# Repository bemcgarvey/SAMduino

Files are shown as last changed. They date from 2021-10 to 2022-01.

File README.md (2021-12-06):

# SAMduino

## A demonstartion board for the ATSAMV71N21B microcontroller.  Includes firmware projects to demonstrate many modules and features.  
  
### There is sample firmware for:
* Basic gpio and interrupts
* DMA
* High speed USB
* QSPI with a SST26VF064B flash
* CAN-FD
* ADC and DAC
* PWM
* True random number generator
* TWI
* RTC
* USB bootloader
* High speed USB mass storage device with QSPI flash
* etc

### All firmware is built in MPLabX with MPLab Harmony 3 and the XC32 compiler.  
### Schematic and PCB were made with KiCAD

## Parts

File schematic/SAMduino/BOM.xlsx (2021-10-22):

Reference | Quantity | Value | Footprint
C1 C5 C6 C8 C9 C11 C14 C16 C17 C18 C19 C21 C22 C24 C25 | 15 | 100n | Capacitor_SMD:C_0402_1005Metric
C7 C10 | 2 | 10uF | Capacitor_SMD:C_0805_2012Metric
C12 C13 | 2 | 22uF | Capacitor_SMD:C_0603_1608Metric
C15 C20 | 2 | 4.7uF | Capacitor_SMD:C_0603_1608Metric
C23 | 1 | 1uF | Capacitor_SMD:C_0402_1005Metric
C28 | 1 | 220n | Capacitor_SMD:C_0603_1608Metric
C2 C3 | 2 | 20p | Capacitor_SMD:C_0603_1608Metric
C26 C27 C29 C30 | 4 | 100n | Capacitor_SMD:C_0603_1608Metric
C4 | 1 | 10p | Capacitor_SMD:C_0603_1608Metric
D1 D2 | 2 | MBR0520LT | Diode_SMD:D_SOD-123
D3 | 1 | Green | LED_SMD:LED_0603_1608Metric
D4 | 1 | Yellow | LED_SMD:LED_0603_1608Metric
D5 | 1 | Red | LED_SMD:LED_0805_2012Metric
D6 | 1 | Green | LED_SMD:LED_0805_2012Metric
D7 | 1 | Blue | LED_SMD:LED_0805_2012Metric
D8 | 1 | Yellow | LED_SMD:LED_0805_2012Metric
D9 D11 | 2 | Red | LED_SMD:LED_0603_1608Metric
IC1 | 1 | ATSAMV71N21B-AABT | SamacSys_Parts:QFP50P1600X1600X160-100N
IC2 | 1 | AZ1117CH-5.0TRG1 | SOT230P700X180-4N
IC3 | 1 | AZ1117IH-3.3TRG1 | SOT230P700X180-4N
IC4 | 1 | SST26VF064B-104V_SM | SamacSys_Parts:SOIC127P794X203-8N
IC5 | 1 | MCP2221-I_SL | SamacSys_Parts:SOIC127P600X175-14N
IC6 | 1 | MCP2542FD-E_SN | SamacSys_Parts:SOIC127P600X175-8N
J1 | 1 | Barrel_Jack_Switch | Connector_BarrelJack:BarrelJack_Wuerth_6941xx301002
J10 | 1 | Conn_02x11_Odd_Even | Connector_PinHeader_2.54mm:PinHeader_2x11_P2.54mm_Vertical
J11 J12 | 2 | Conn_02x09_Odd_Even | Connector_PinHeader_2.54mm:PinHeader_2x09_P2.54mm_Vertical
J15 J17 J19 | 3 | Conn_02x03_Odd_Even | Connector_PinHeader_2.54mm:PinHeader_2x03_P2.54mm_Vertical
J2 J14 J18 | 3 | Conn_02x02_Odd_Even | Connector_PinHeader_2.54mm:PinHeader_2x02_P2.54mm_Vertical
J20 | 1 | Conn_01x08 | Connector_PinHeader_2.54mm:PinHeader_1x08_P2.54mm_Horizontal
J3 | 1 | USB_B_Micro | Connector_USB:USB_Micro-B_Amphenol_10104110_Horizontal
J4 | 1 | USB_B_Mini | Connector_USB:USB_Mini-B_Wuerth_65100516121_Horizontal
J5 J7 J8 J13 J16 | 5 | Conn_01x02 | Connector_PinHeader_2.54mm:PinHeader_1x02_P2.54mm_Vertical
J6 | 1 | Screw_Terminal_01x02 | SamacSys_Parts:1725656
J9 | 1 | Conn_02x07_Odd_Even | Connector_PinHeader_2.54mm:PinHeader_2x07_P2.54mm_Vertical
L1 | 1 | 10uH | Inductor_SMD:L_0603_1608Metric
L2 L3 L4 | 3 | 470R | Inductor_SMD:L_0603_1608Metric
R1 | 1 | 5k62 ± 1% | Resistor_SMD:R_0402_1005Metric
R14 R15 | 2 | 4k7 | Resistor_SMD:R_0603_1608Metric
R5 R6 R9 R10 R11 R12 R18 | 7 | 220R | Resistor_SMD:R_0603_1608Metric
R19 | 1 | 330R | Resistor_SMD:R_0603_1608Metric
R2 | 1 | 22k | Resistor_SMD:R_0603_1608Metric
R13 R20 | 2 | 10k | Resistor_SMD:R_0603_1608Metric
R3 | 1 | 15k | Resistor_SMD:R_0603_1608Metric
R4 R8 R16 R17 | 4 | 100k | Resistor_SMD:R_0603_1608Metric
R7 | 1 | 120R | Resistor_SMD:R_0805_2012Metric
SW1 SW2 | 2 | SW_MEC_5E | SamacSys_Parts:FSM16JH
SW3 | 1 | MCLR | SamacSys_Parts:PTS647SK38SMTR2LFS
SW4 | 1 | ERASE | SamacSys_Parts:PTS647SK38SMTR2LFS
X1 | 1 | 12 MHz | SamacSys_Parts:ASTMUPCE3312000MHZLJET
X2 | 1 | 32.768 kHz 12.5 pF | SamacSys_Parts:CM9VT1A

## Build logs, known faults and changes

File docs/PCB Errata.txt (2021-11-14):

SAMduino errata

V1.0 pcb
	Button labels are reversed.  Left button is PD8, right is PA20
	CAN connector - CANL and CANH are mislabeled.  They are reversed.

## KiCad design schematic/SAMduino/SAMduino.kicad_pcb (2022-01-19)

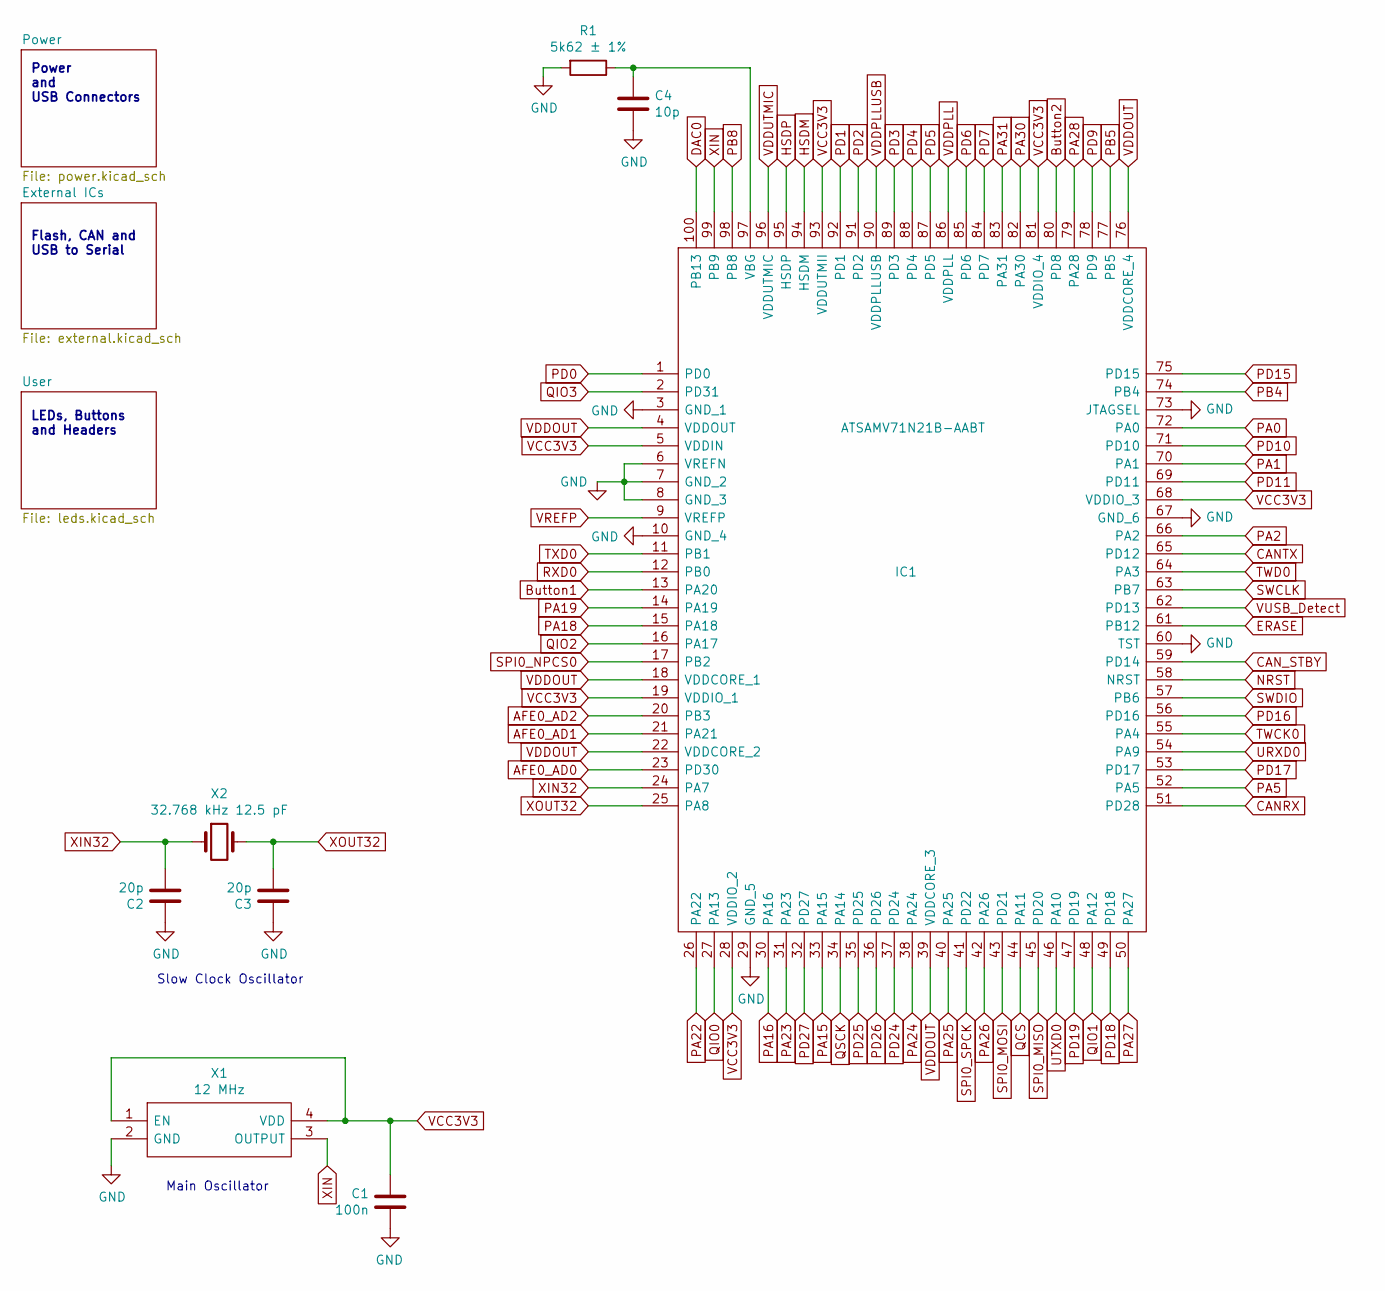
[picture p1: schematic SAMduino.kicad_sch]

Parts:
C1: 100n; C_0402_1005Metric
C2, C3: 20p; C_0603_1608Metric
C4: 10p; C_0603_1608Metric
IC1: ATSAMV71N21B-AABT; QFP50P1600X1600X160-100N; Mouser Part Number 556-ATSAMV71N21BAABT
R1: 5k62 ± 1%; R_0402_1005Metric
X1: 12 MHz; ASTMUPCE3312000MHZLJET
X2: 32.768 kHz 12.5 pF; CM9VT1A; Part Number CM9V-T1A-32.768kHz-12.5pF-20PPM-TA-QC; Mouser Part Number 428-202257-MC01

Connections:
AFE0_AD0: IC1.23 (PD30); also elsewhere on the board
AFE0_AD1: IC1.21 (PA21); also elsewhere on the board
AFE0_AD2: IC1.20 (PB3); also elsewhere on the board
Button1: IC1.13 (PA20); also elsewhere on the board
Button2: IC1.80 (PD8); also elsewhere on the board
CANRX: IC1.51 (PD28); also elsewhere on the board
CANTX: IC1.65 (PD12); also elsewhere on the board
CAN_STBY: IC1.59 (PD14); also elsewhere on the board
DAC0: IC1.100 (PB13); also elsewhere on the board
ERASE: IC1.61 (PB12); also elsewhere on the board
GND: C1.2, C2.1, C3.1, C4.2, IC1.3 (GND_1), IC1.6 (VREFN), IC1.7 (GND_2), IC1.8 (GND_3), IC1.10 (GND_4), IC1.29 (GND_5), IC1.60 (TST), IC1.67 (GND_6), IC1.73 (JTAGSEL), R1.2, X1.2 (GND); also elsewhere on the board
HSDM: IC1.94 (HSDM); also elsewhere on the board
HSDP: IC1.95 (HSDP); also elsewhere on the board
NRST: IC1.58 (NRST); also elsewhere on the board
unnamed: C4.1, IC1.97 (VBG), R1.1
PA0: IC1.72 (PA0); also elsewhere on the board
PA1: IC1.70 (PA1); also elsewhere on the board
PA2: IC1.66 (PA2); also elsewhere on the board
PA5: IC1.52 (PA5); also elsewhere on the board
PA15: IC1.33 (PA15); also elsewhere on the board
PA16: IC1.30 (PA16); also elsewhere on the board
PA18: IC1.15 (PA18); also elsewhere on the board
PA19: IC1.14 (PA19); also elsewhere on the board
PA22: IC1.26 (PA22); also elsewhere on the board
PA23: IC1.31 (PA23); also elsewhere on the board
PA24: IC1.38 (PA24); also elsewhere on the board
PA25: IC1.40 (PA25); also elsewhere on the board
PA26: IC1.42 (PA26); also elsewhere on the board
PA27: IC1.50 (PA27); also elsewhere on the board
PA28: IC1.79 (PA28); also elsewhere on the board
PA30: IC1.82 (PA30); also elsewhere on the board
PA31: IC1.83 (PA31); also elsewhere on the board
PB4: IC1.74 (PB4); also elsewhere on the board
PB5: IC1.77 (PB5); also elsewhere on the board
PB8: IC1.98 (PB8); also elsewhere on the board
PD0: IC1.1 (PD0); also elsewhere on the board
PD1: IC1.92 (PD1); also elsewhere on the board
PD2: IC1.91 (PD2); also elsewhere on the board
PD3: IC1.89 (PD3); also elsewhere on the board
PD4: IC1.88 (PD4); also elsewhere on the board
PD5: IC1.87 (PD5); also elsewhere on the board
PD6: IC1.85 (PD6); also elsewhere on the board
PD7: IC1.84 (PD7); also elsewhere on the board
PD9: IC1.78 (PD9); also elsewhere on the board
PD10: IC1.71 (PD10); also elsewhere on the board
PD11: IC1.69 (PD11); also elsewhere on the board
PD15: IC1.75 (PD15); also elsewhere on the board
PD16: IC1.56 (PD16); also elsewhere on the board
PD17: IC1.53 (PD17); also elsewhere on the board
PD18: IC1.49 (PD18); also elsewhere on the board
PD19: IC1.47 (PD19); also elsewhere on the board
PD24: IC1.37 (PD24); also elsewhere on the board
PD25: IC1.35 (PD25); also elsewhere on the board
PD26: IC1.36 (PD26); also elsewhere on the board
PD27: IC1.32 (PD27); also elsewhere on the board
QCS: IC1.44 (PA11); also elsewhere on the board
QIO0: IC1.27 (PA13); also elsewhere on the board
QIO1: IC1.48 (PA12); also elsewhere on the board
QIO2: IC1.16 (PA17); also elsewhere on the board
QIO3: IC1.2 (PD31); also elsewhere on the board
QSCK: IC1.34 (PA14); also elsewhere on the board
RXD0: IC1.12 (PB0); also elsewhere on the board
SPI0_MISO: IC1.45 (PD20); also elsewhere on the board
SPI0_MOSI: IC1.43 (PD21); also elsewhere on the board
SPI0_NPCS0: IC1.17 (PB2); also elsewhere on the board
SPI0_SPCK: IC1.41 (PD22); also elsewhere on the board
SWCLK: IC1.63 (PB7); also elsewhere on the board
SWDIO: IC1.57 (PB6); also elsewhere on the board
TWCK0: IC1.55 (PA4); also elsewhere on the board
TWD0: IC1.64 (PA3); also elsewhere on the board
TXD0: IC1.11 (PB1); also elsewhere on the board
URXD0: IC1.54 (PA9); also elsewhere on the board
UTXD0: IC1.46 (PA10); also elsewhere on the board
VCC3V3: C1.1, IC1.5 (VDDIN), IC1.19 (VDDIO_1), IC1.28 (VDDIO_2), IC1.68 (VDDIO_3), IC1.81 (VDDIO_4), IC1.93 (VDDUTMII), X1.1 (EN), X1.4 (VDD); also elsewhere on the board
VDDOUT: IC1.4 (VDDOUT), IC1.18 (VDDCORE_1), IC1.22 (VDDCORE_2), IC1.39 (VDDCORE_3), IC1.76 (VDDCORE_4); also elsewhere on the board
VDDPLL: IC1.86 (VDDPLL); also elsewhere on the board
VDDPLLUSB: IC1.90 (VDDPLLUSB); also elsewhere on the board
VDDUTMIC: IC1.96 (VDDUTMIC); also elsewhere on the board
VREFP: IC1.9 (VREFP); also elsewhere on the board
VUSB_Detect: IC1.62 (PD13); also elsewhere on the board
XIN: IC1.99 (PB9), X1.3 (OUTPUT)
XIN32: C2.2, IC1.24 (PA7), X2.1
XOUT32: C3.2, IC1.25 (PA8), X2.2

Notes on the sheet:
Main Oscillator
Flash, CAN and USB to Serial
LEDs, Buttons and Headers
Slow Clock Oscillator
Power and USB Connectors

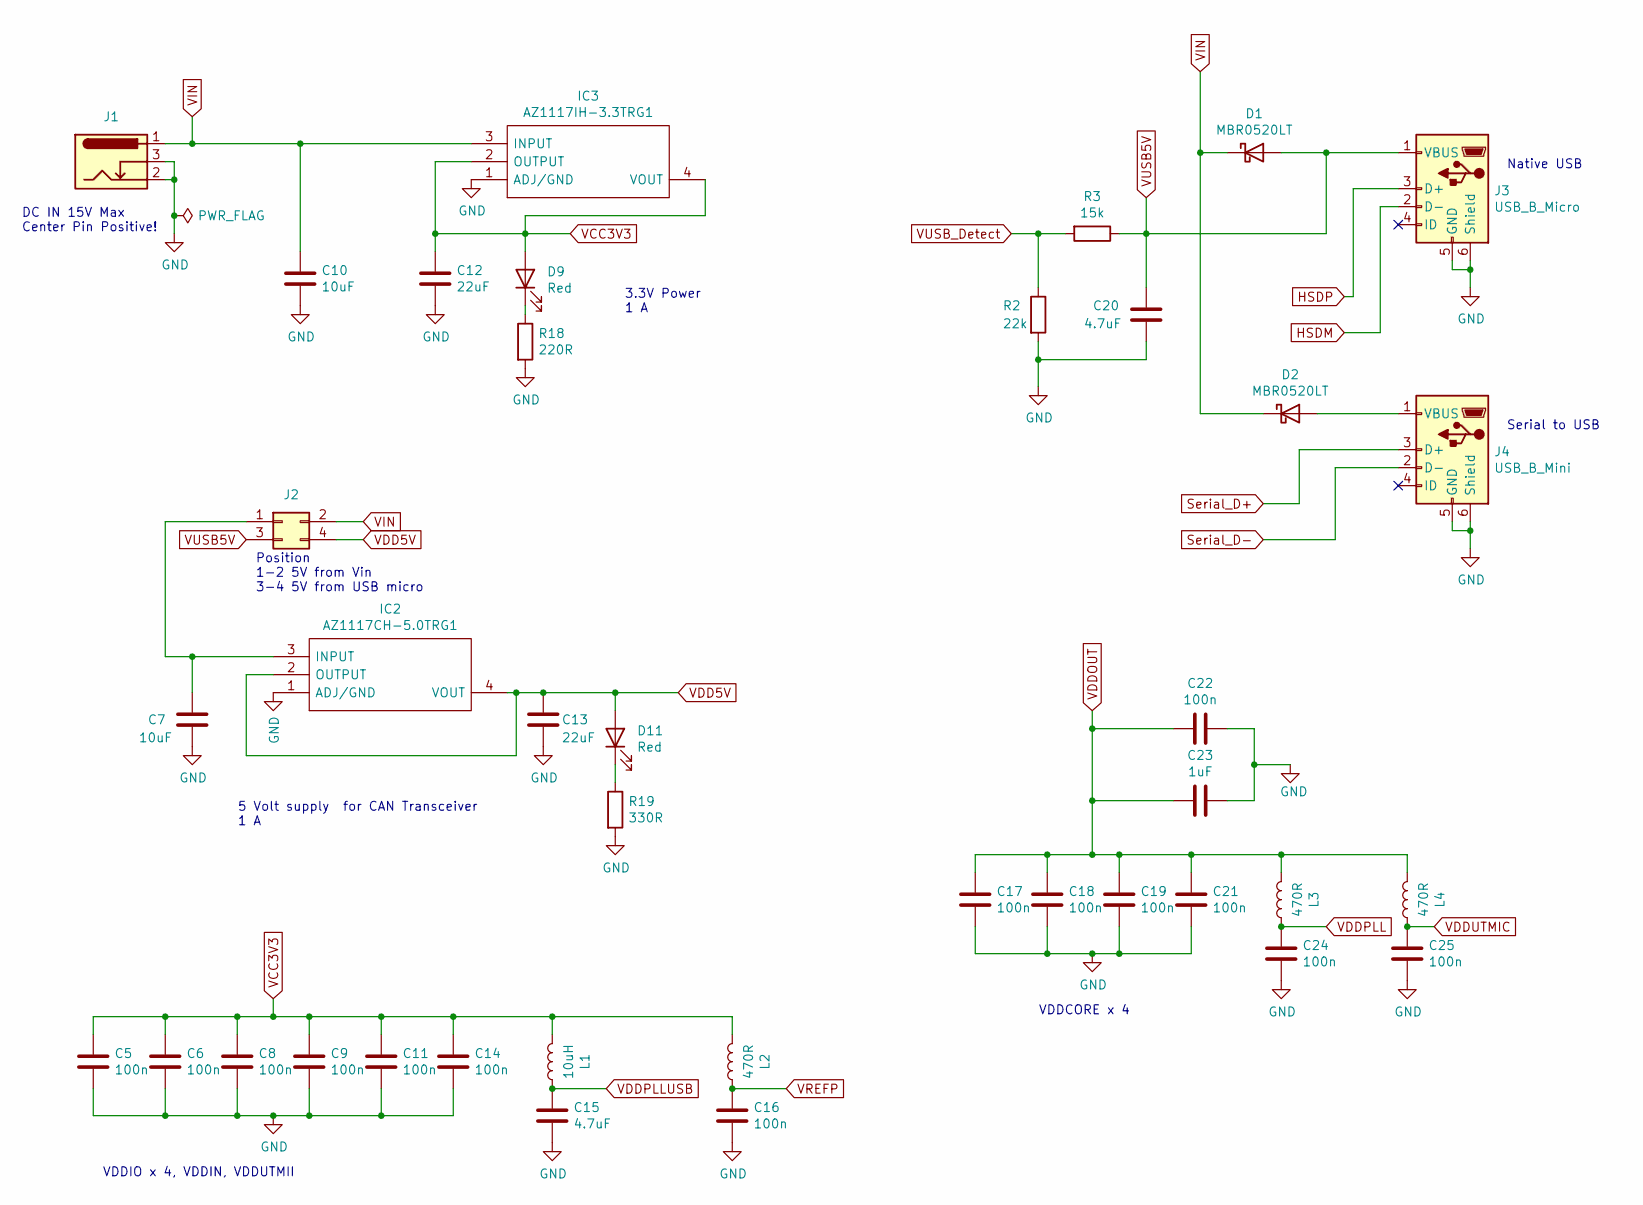
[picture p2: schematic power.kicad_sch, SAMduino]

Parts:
C5, C6, C8, C9, C11, C14, C16, C17, C18, C19, C21, C22, C24, C25: 100n; C_0402_1005Metric
C7, C10: 10uF; C_0805_2012Metric
C12, C13: 22uF; C_0603_1608Metric
C15, C20: 4.7uF; C_0603_1608Metric
C23: 1uF; C_0402_1005Metric
D1, D2: MBR0520LT; D_SOD-123
D9, D11: Red; LED_0603_1608Metric
IC2: AZ1117CH-5.0TRG1; SOT230P700X180-4N; Mouser Part Number 621-AZ1117CH-5.0TRG1
IC3: AZ1117IH-3.3TRG1; SOT230P700X180-4N; Mouser Part Number 621-AZ1117IH-3.3TRG1
J1: Barrel_Jack_Switch; BarrelJack_Wuerth_6941xx301002
J2: Conn_02x02_Odd_Even; PinHeader_2x02_P2.54mm_Vertical
J3: USB_B_Micro; USB_Micro-B_Amphenol_10104110_Horizontal
J4: USB_B_Mini; USB_Mini-B_Wuerth_65100516121_Horizontal
L1: 10uH; L_0603_1608Metric
L2, L3, L4: 470R; L_0603_1608Metric
R2: 22k; R_0603_1608Metric
R3: 15k; R_0603_1608Metric
R18: 220R; R_0603_1608Metric
R19: 330R; R_0603_1608Metric

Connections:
GND: C5.2, C6.2, C7.2, C8.2, C9.2, C10.2, C11.2, C12.2, C13.2, C14.2, C15.2, C16.2, C17.2, C18.2, C19.2, C20.2, C21.2, C22.1, C23.1, C24.2, C25.2, IC2.1 (ADJ/GND), IC3.1 (ADJ/GND), J1.2, J1.3, J3.5 (GND), J3.6 (Shield), J4.5 (GND), J4.6 (Shield), R2.2, R18.2, R19.2; also elsewhere on the board
HSDM: J3.2 (D-); also elsewhere on the board
HSDP: J3.3 (D+); also elsewhere on the board
unnamed: C7.1, IC2.3 (INPUT), J2.1
unnamed: D2.2 (A), J4.1 (VBUS)
unnamed: D9.1 (K), R18.1
unnamed: D11.1 (K), R19.1
Serial_D+: J4.3 (D+); also elsewhere on the board
Serial_D-: J4.2 (D-); also elsewhere on the board
VCC3V3: C5.1, C6.1, C8.1, C9.1, C11.1, C12.1, C14.1, D9.2 (A), IC3.2 (OUTPUT), IC3.4 (VOUT), L1.2, L2.2; also elsewhere on the board
VDD5V: C13.1, D11.2 (A), IC2.2 (OUTPUT), IC2.4 (VOUT), J2.4; also elsewhere on the board
VDDOUT: C17.1, C18.1, C19.1, C21.1, C22.2, C23.2, L3.2, L4.2; also elsewhere on the board
VDDPLL: C24.1, L3.1; also elsewhere on the board
VDDPLLUSB: C15.1, L1.1; also elsewhere on the board
VDDUTMIC: C25.1, L4.1; also elsewhere on the board
VIN: C10.1, D1.1 (K), D2.1 (K), IC3.3 (INPUT), J1.1, J2.2; also elsewhere on the board
VREFP: C16.1, L2.1; also elsewhere on the board
VUSB5V: C20.1, D1.2 (A), J2.3, J3.1 (VBUS), R3.1
VUSB_Detect: R2.1, R3.2; also elsewhere on the board

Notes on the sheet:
Serial to USB
Position 1-2 5V from Vin 3-4 5V from USB micro
DC IN 15V Max Center Pin Positive!
VDDIO x 4, VDDIN, VDDUTMII
VDDCORE x 4
3.3V Power 1 A
5 Volt supply for CAN Transceiver 1 A
Native USB

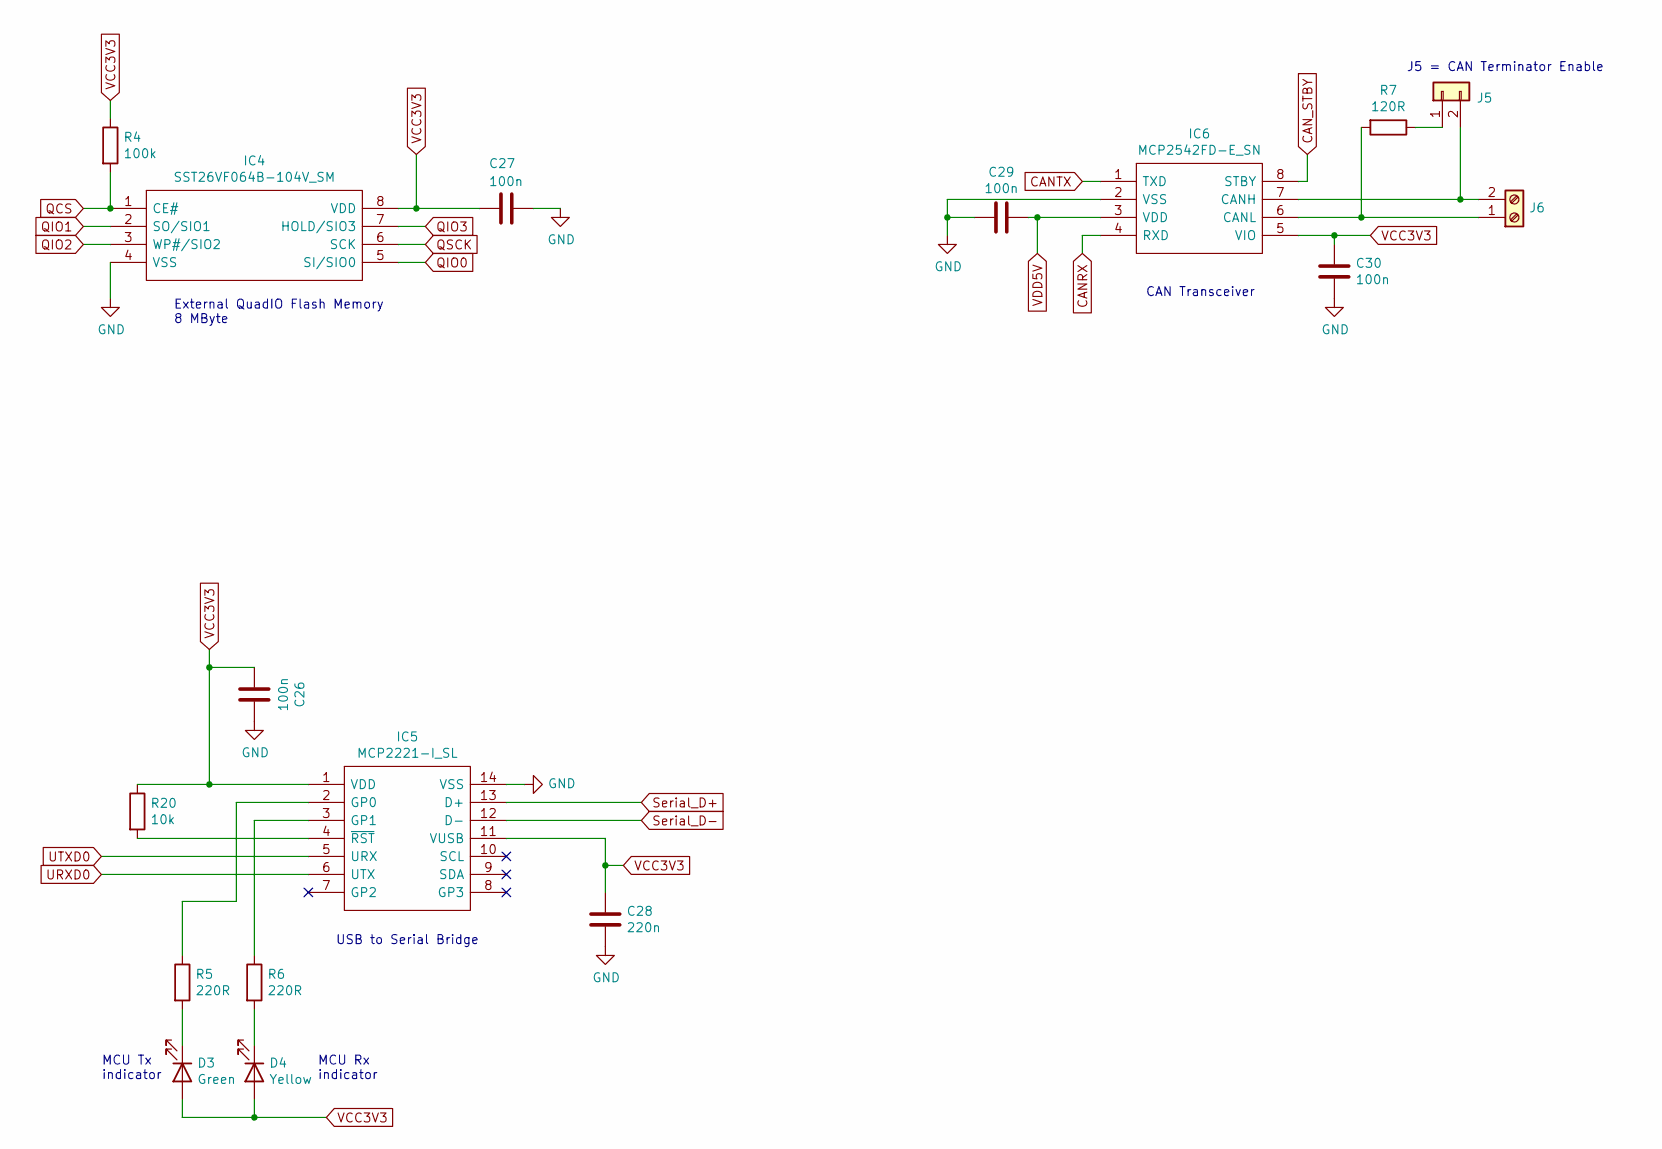
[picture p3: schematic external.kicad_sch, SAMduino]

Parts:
C26, C27, C29, C30: 100n; C_0603_1608Metric
C28: 220n; C_0603_1608Metric
D3: Green; LED_0603_1608Metric
D4: Yellow; LED_0603_1608Metric
IC4: SST26VF064B-104V_SM; SOIC127P794X203-8N; Mouser Part Number 579-26VF064B-104V/SM
IC5: MCP2221-I_SL; SOIC127P600X175-14N; Mouser Part Number 579-MCP2221-I/SL
IC6: MCP2542FD-E_SN; SOIC127P600X175-8N; Mouser Part Number 579-MCP2542FD-E/SN
J5: Conn_01x02; PinHeader_1x02_P2.54mm_Vertical
J6: Screw_Terminal_01x02; 1725656
R4: 100k; R_0603_1608Metric
R5, R6: 220R; R_0603_1608Metric
R7: 120R; R_0805_2012Metric
R20: 10k; R_0603_1608Metric

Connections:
CANRX: IC6.4 (RXD); also elsewhere on the board
CANTX: IC6.1 (TXD); also elsewhere on the board
CAN_STBY: IC6.8 (STBY); also elsewhere on the board
GND: C26.1, C27.1, C28.2, C29.1, C30.2, IC4.4 (VSS), IC5.14 (VSS), IC6.2 (VSS); also elsewhere on the board
unnamed: D3.1 (K), R5.2
unnamed: D4.1 (K), R6.2
unnamed: IC5.2 (GP0), R5.1
unnamed: IC5.3 (GP1), R6.1
unnamed: IC5.4 (~RST), R20.2
unnamed: IC6.6 (CANL), J6.1, R7.2
unnamed: IC6.7 (CANH), J5.2, J6.2
unnamed: J5.1, R7.1
QCS: IC4.1 (CE#), R4.2; also elsewhere on the board
QIO0: IC4.5 (SI/SIO0); also elsewhere on the board
QIO1: IC4.2 (SO/SIO1); also elsewhere on the board
QIO2: IC4.3 (WP#/SIO2); also elsewhere on the board
QIO3: IC4.7 (HOLD/SIO3); also elsewhere on the board
QSCK: IC4.6 (SCK); also elsewhere on the board
Serial_D+: IC5.13 (D+); also elsewhere on the board
Serial_D-: IC5.12 (D-); also elsewhere on the board
URXD0: IC5.6 (UTX); also elsewhere on the board
UTXD0: IC5.5 (URX); also elsewhere on the board
VCC3V3: C26.2, C27.2, C28.1, C30.1, D3.2 (A), D4.2 (A), IC4.8 (VDD), IC5.1 (VDD), IC5.11 (VUSB), IC6.5 (VIO), R4.1, R20.1; also elsewhere on the board
VDD5V: C29.2, IC6.3 (VDD); also elsewhere on the board

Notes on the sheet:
USB to Serial Bridge
MCU Tx indicator
External QuadIO Flash Memory 8 MByte
MCU Rx indicator
J5 = CAN Terminator Enable
CAN Transceiver

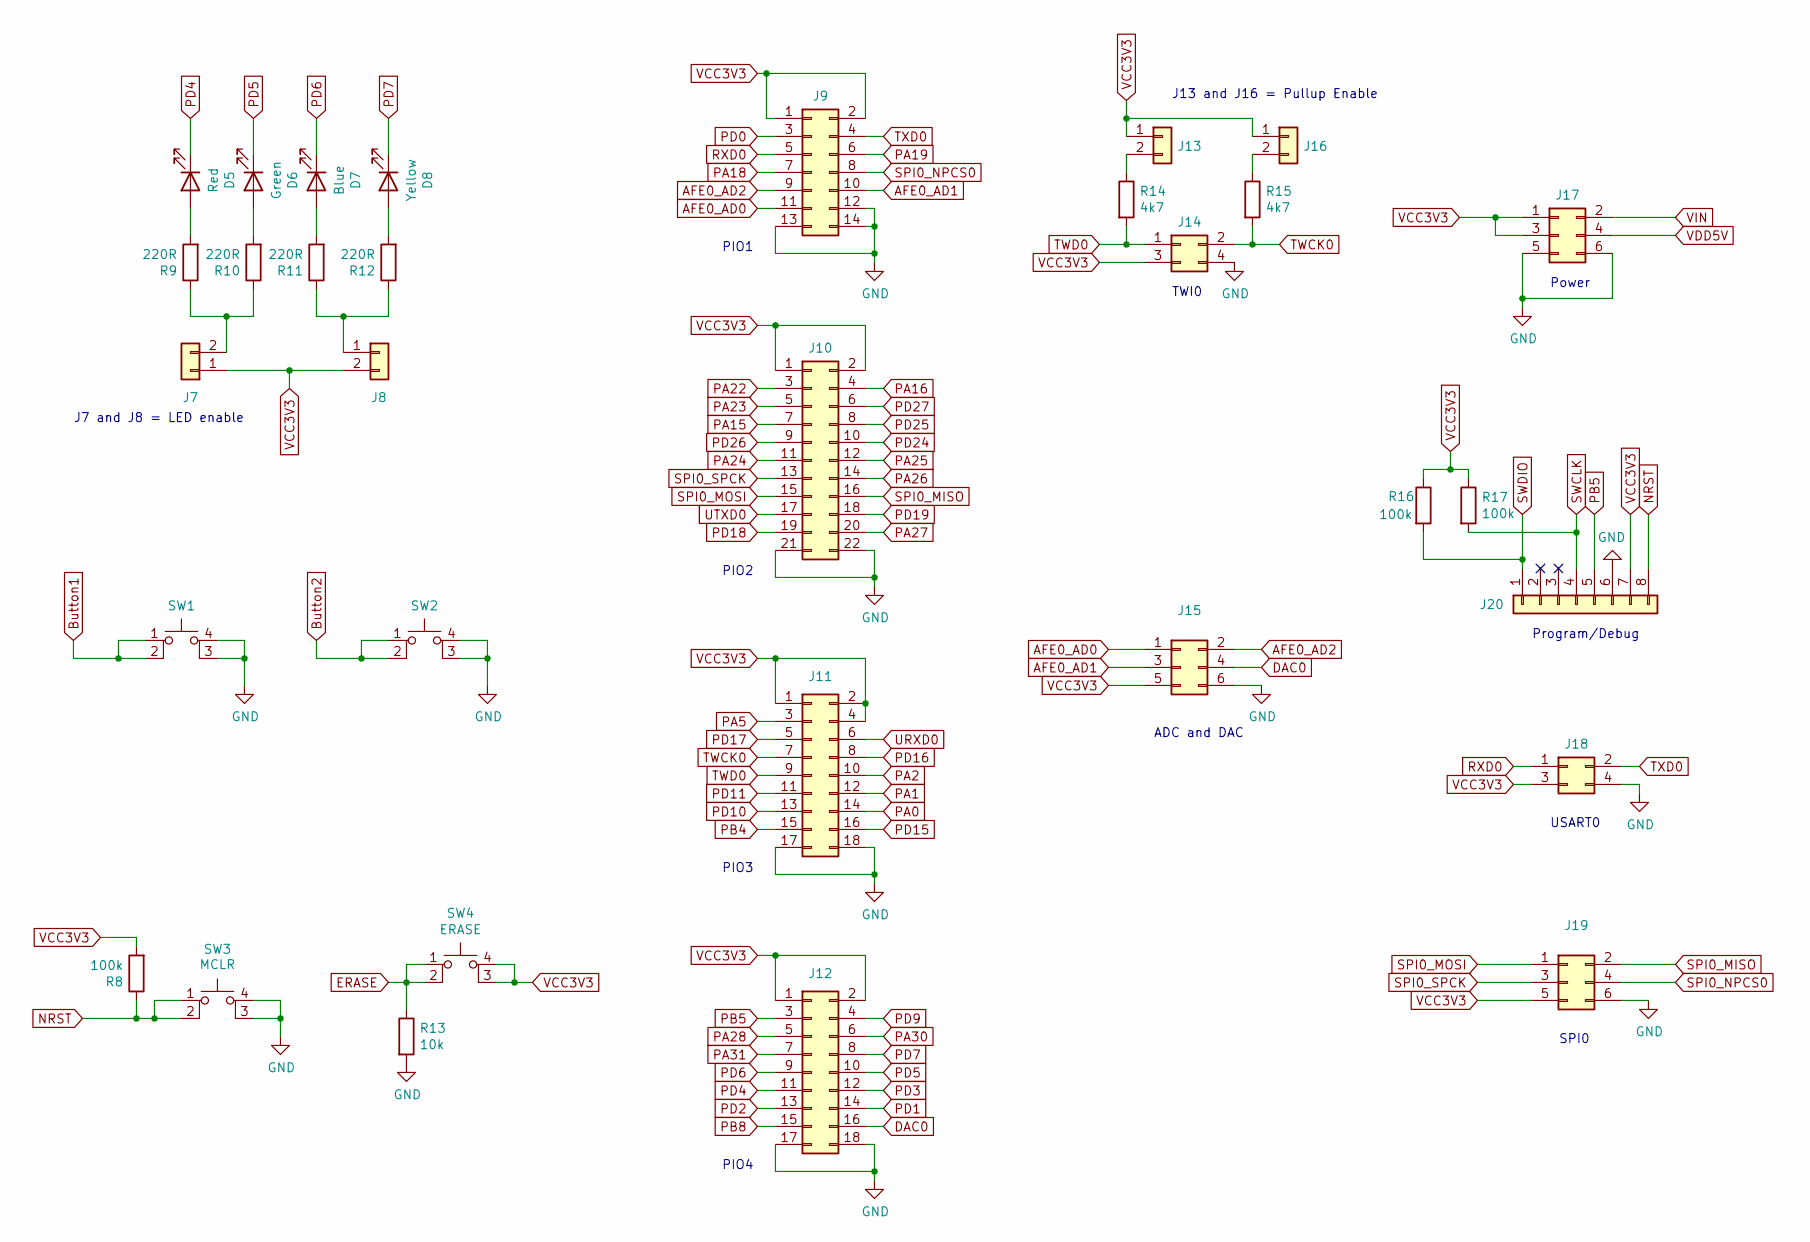
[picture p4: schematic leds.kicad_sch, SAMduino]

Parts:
D5: Red; LED_0805_2012Metric
D6: Green; LED_0805_2012Metric
D7: Blue; LED_0805_2012Metric
D8: Yellow; LED_0805_2012Metric
J7, J8, J13, J16: Conn_01x02; PinHeader_1x02_P2.54mm_Vertical
J9: Conn_02x07_Odd_Even; PinHeader_2x07_P2.54mm_Vertical
J10: Conn_02x11_Odd_Even; PinHeader_2x11_P2.54mm_Vertical
J11, J12: Conn_02x09_Odd_Even; PinHeader_2x09_P2.54mm_Vertical
J14, J18: Conn_02x02_Odd_Even; PinHeader_2x02_P2.54mm_Vertical
J15, J17, J19: Conn_02x03_Odd_Even; PinHeader_2x03_P2.54mm_Vertical
J20: Conn_01x08; PinHeader_1x08_P2.54mm_Horizontal
R8, R16, R17: 100k; R_0603_1608Metric
R9, R10, R11, R12: 220R; R_0603_1608Metric
R13: 10k; R_0603_1608Metric
R14, R15: 4k7; R_0603_1608Metric
SW1, SW2: SW_MEC_5E; FSM16JH
SW3: MCLR; PTS647SK38SMTR2LFS
SW4: ERASE; PTS647SK38SMTR2LFS

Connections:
AFE0_AD0: J9.11, J15.1; also elsewhere on the board
AFE0_AD1: J9.10, J15.3; also elsewhere on the board
AFE0_AD2: J9.9, J15.2; also elsewhere on the board
Button1: SW1.1, SW1.2; also elsewhere on the board
Button2: SW2.1, SW2.2; also elsewhere on the board
DAC0: J12.16, J15.4; also elsewhere on the board
ERASE: R13.1, SW4.1, SW4.2; also elsewhere on the board
GND: J9.12, J9.13, J9.14, J10.21, J10.22, J11.17, J11.18, J12.17, J12.18, J14.4, J15.6, J17.5, J17.6, J18.4, J19.6, J20.6, R13.2, SW1.3 (K), SW1.4 (A), SW2.3 (K), SW2.4 (A), SW3.3 (K), SW3.4 (A); also elsewhere on the board
NRST: J20.8, R8.1, SW3.1, SW3.2; also elsewhere on the board
unnamed: D5.2 (A), R9.2
unnamed: D6.2 (A), R10.2
unnamed: D7.2 (A), R11.2
unnamed: D8.2 (A), R12.2
unnamed: J7.2, R9.1, R10.1
unnamed: J8.1, R11.1, R12.1
unnamed: J13.2, R14.1
unnamed: J16.2, R15.1
PA0: J11.14; also elsewhere on the board
PA1: J11.12; also elsewhere on the board
PA2: J11.10; also elsewhere on the board
PA5: J11.3; also elsewhere on the board
PA15: J10.7; also elsewhere on the board
PA16: J10.4; also elsewhere on the board
PA18: J9.7; also elsewhere on the board
PA19: J9.6; also elsewhere on the board
PA22: J10.3; also elsewhere on the board
PA23: J10.5; also elsewhere on the board
PA24: J10.11; also elsewhere on the board
PA25: J10.12; also elsewhere on the board
PA26: J10.14; also elsewhere on the board
PA27: J10.20; also elsewhere on the board
PA28: J12.5; also elsewhere on the board
PA30: J12.6; also elsewhere on the board
PA31: J12.7; also elsewhere on the board
PB4: J11.15; also elsewhere on the board
PB5: J12.3, J20.5; also elsewhere on the board
PB8: J12.15; also elsewhere on the board
PD0: J9.3; also elsewhere on the board
PD1: J12.14; also elsewhere on the board
PD2: J12.13; also elsewhere on the board
PD3: J12.12; also elsewhere on the board
PD4: D5.1 (K), J12.11; also elsewhere on the board
PD5: D6.1 (K), J12.10; also elsewhere on the board
PD6: D7.1 (K), J12.9; also elsewhere on the board
PD7: D8.1 (K), J12.8; also elsewhere on the board
PD9: J12.4; also elsewhere on the board
PD10: J11.13; also elsewhere on the board
PD11: J11.11; also elsewhere on the board
PD15: J11.16; also elsewhere on the board
PD16: J11.8; also elsewhere on the board
PD17: J11.5; also elsewhere on the board
PD18: J10.19; also elsewhere on the board
PD19: J10.18; also elsewhere on the board
PD24: J10.10; also elsewhere on the board
PD25: J10.8; also elsewhere on the board
PD26: J10.9; also elsewhere on the board
PD27: J10.6; also elsewhere on the board
RXD0: J9.5, J18.1; also elsewhere on the board
SPI0_MISO: J10.16, J19.2; also elsewhere on the board
SPI0_MOSI: J10.15, J19.1; also elsewhere on the board
SPI0_NPCS0: J9.8, J19.4; also elsewhere on the board
SPI0_SPCK: J10.13, J19.3; also elsewhere on the board
SWCLK: J20.4, R17.2; also elsewhere on the board
SWDIO: J20.1, R16.2; also elsewhere on the board
TWCK0: J11.7, J14.2, R15.2; also elsewhere on the board
TWD0: J11.9, J14.1, R14.2; also elsewhere on the board
TXD0: J9.4, J18.2; also elsewhere on the board
URXD0: J11.6; also elsewhere on the board
UTXD0: J10.17; also elsewhere on the board
VCC3V3: J7.1, J8.2, J9.1, J9.2, J10.1, J10.2, J11.1, J11.2, J11.4, J12.1, J12.2, J13.1, J14.3, J15.5, J16.1, J17.1, J17.3, J18.3, J19.5, J20.7, R8.2, R16.1, R17.1, SW4.3 (K), SW4.4 (A); also elsewhere on the board
VDD5V: J17.4; also elsewhere on the board
VIN: J17.2; also elsewhere on the board

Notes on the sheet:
J7 and J8 = LED enable
SPI0
PIO1
TWI0
PIO2
PIO3
Power
ADC and DAC
PIO4
USART0
Program/Debug
J13 and J16 = Pullup Enable

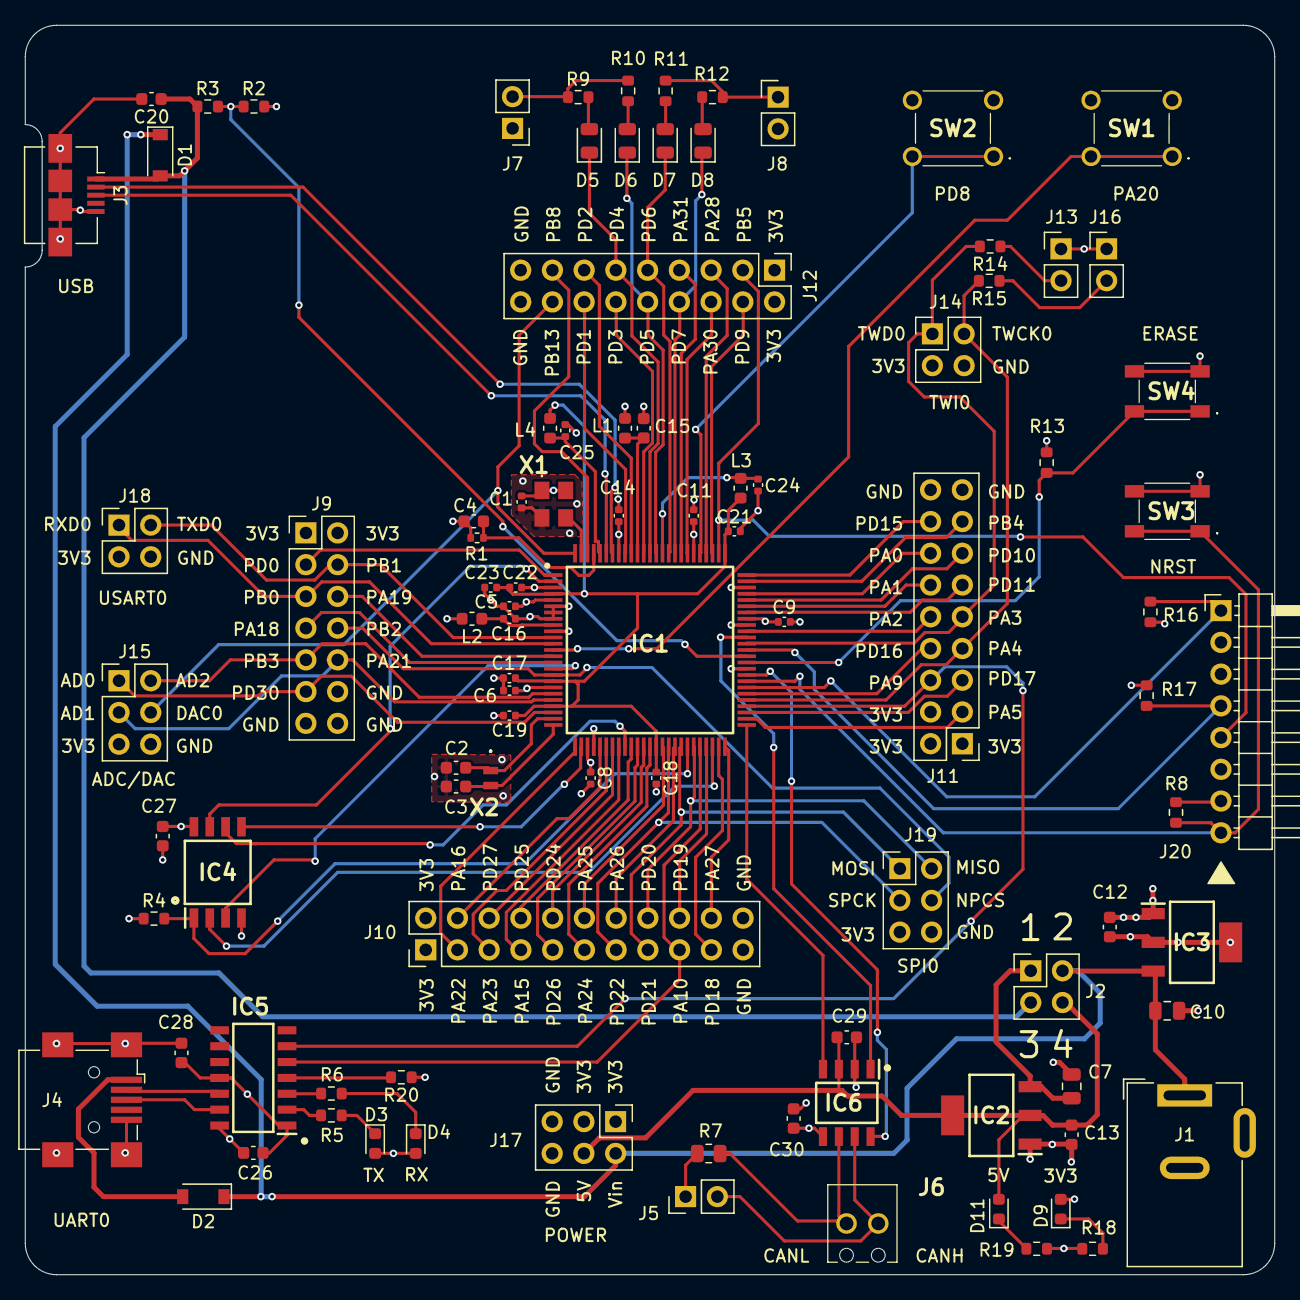
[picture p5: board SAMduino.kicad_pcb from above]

Board: 4 copper layers, 100.0 x 100.0 mm, 96 parts (0 on the bottom side), 108 nets.

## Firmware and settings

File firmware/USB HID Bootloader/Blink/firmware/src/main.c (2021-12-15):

/*******************************************************************************
  Main Source File

  Company:
    Microchip Technology Inc.

  File Name:
    main.c

  Summary:
    This file contains the "main" function for a project.

  Description:
    This file contains the "main" function for a project.  The
    "main" function calls the "SYS_Initialize" function to initialize the state
    machines of all modules in the system
 *******************************************************************************/

// *****************************************************************************
// *****************************************************************************
// Section: Included Files
// *****************************************************************************
// *****************************************************************************

#include <stddef.h>                     // Defines NULL
#include <stdbool.h>                    // Defines true
#include <stdlib.h>                     // Defines EXIT_FAILURE
#include "definitions.h"                // SYS function prototypes


// *****************************************************************************
// *****************************************************************************
// Section: Main Entry Point
// *****************************************************************************
// *****************************************************************************
#define BTL_TRIGGER_RAM_START   0x20400000
static uint32_t *ramStart = (uint32_t *) BTL_TRIGGER_RAM_START;


//Function at non-contiguous memory location to test bootloaders
int __attribute__((address(0x41A000))) calculate(void) {
    int i;
    int sum = 0;
    for (i = 0; i < 345; ++i) {
        sum += i;
    }
    return sum;
}

//A simple application to demonstrate firmware bootload trigger
//Must set Application Start Address to 0x4040000 in Harmony Project | linker config
// and disable programming fuses
int main ( void )
{
    /* Initialize all modules */
    SYS_Initialize ( NULL );
    LED_Clear();
    SYSTICK_TimerStart();
    while ( true )
    {
        SYSTICK_DelayMs(1000);
        LED_Toggle();
        if (Boot_Get() == 0) {
            ramStart[0] = 0x12345678;
            ramStart[1] = 0x98765432;
            DCACHE_CLEAN();  //Essential
            NVIC_SystemReset();
        }
        int result = calculate();
        result = result + 10;
    }

    /* Execution should not come here during normal operation */

    return ( EXIT_FAILURE );
}


/*******************************************************************************
 End of File
*/

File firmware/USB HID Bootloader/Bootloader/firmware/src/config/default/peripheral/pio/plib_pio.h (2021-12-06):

/*******************************************************************************
  PIO PLIB

  Company:
    Microchip Technology Inc.

  File Name:
    plib_pio.h

  Summary:
    PIO PLIB Header File

  Description:
    This library provides an interface to control and interact with Parallel
    Input/Output controller (PIO) module.

*******************************************************************************/

/*******************************************************************************
* Copyright (C) 2018 Microchip Technology Inc. and its subsidiaries.
*
* Subject to your compliance with these terms, you may use Microchip software
* and any derivatives exclusively with Microchip products. It is your
* responsibility to comply with third party license terms applicable to your
* use of third party software (including open source software) that may
* accompany Microchip software.
*
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
* IN NO EVENT WILL MICROCHIP BE LIABLE FOR ANY INDIRECT, SPECIAL, PUNITIVE,
* INCIDENTAL OR CONSEQUENTIAL LOSS, DAMAGE, COST OR EXPENSE OF ANY KIND
* WHATSOEVER RELATED TO THE SOFTWARE, HOWEVER CAUSED, EVEN IF MICROCHIP HAS
* BEEN ADVISED OF THE POSSIBILITY OR THE DAMAGES ARE FORESEEABLE. TO THE
* FULLEST EXTENT ALLOWED BY LAW, MICROCHIP'S TOTAL LIABILITY ON ALL CLAIMS IN
* ANY WAY RELATED TO THIS SOFTWARE WILL NOT EXCEED THE AMOUNT OF FEES, IF ANY,
* THAT YOU HAVE PAID DIRECTLY TO MICROCHIP FOR THIS SOFTWARE.
*******************************************************************************/

#ifndef PLIB_PIO_H
#define PLIB_PIO_H

#include "device.h"
#include <stdint.h>
#include <stdbool.h>
#include <stddef.h>

// DOM-IGNORE-BEGIN
#ifdef __cplusplus  // Provide C++ Compatibility

    extern "C" {

#endif
// DOM-IGNORE-END

// *****************************************************************************
// *****************************************************************************
// Section: Data types and constants
// *****************************************************************************
// *****************************************************************************


/*** Macros for Bootload pin ***/
#define Bootload_Set()               (PIOA_REGS->PIO_SODR = (1<<20))
#define Bootload_Clear()             (PIOA_REGS->PIO_CODR = (1<<20))
#define Bootload_Toggle()            (PIOA_REGS->PIO_ODSR ^= (1<<20))
#define Bootload_OutputEnable()      (PIOA_REGS->PIO_OER = (1<<20))
#define Bootload_InputEnable()       (PIOA_REGS->PIO_ODR = (1<<20))
#define Bootload_Get()               ((PIOA_REGS->PIO_PDSR >> 20) & 0x1)
#define Bootload_PIN                  PIO_PIN_PA20

/*** Macros for LED pin ***/
#define LED_Set()               (PIOD_REGS->PIO_SODR = (1<<7))
#define LED_Clear()             (PIOD_REGS->PIO_CODR = (1<<7))
#define LED_Toggle()            (PIOD_REGS->PIO_ODSR ^= (1<<7))
#define LED_OutputEnable()      (PIOD_REGS->PIO_OER = (1<<7))
#define LED_InputEnable()       (PIOD_REGS->PIO_ODR = (1<<7))
#define LED_Get()               ((PIOD_REGS->PIO_PDSR >> 7) & 0x1)
#define LED_PIN                  PIO_PIN_PD7


// *****************************************************************************
/* PIO Port

  Summary:
    Identifies the available PIO Ports.

  Description:
    This enumeration identifies the available PIO Ports.

  Remarks:
    The caller should not rely on the specific numbers assigned to any of
    these values as they may change from one processor to the next.

    Not all ports are available on all devices.  Refer to the specific
    device data sheet to determine which ports are supported.
*/

typedef enum
{
    PIO_PORT_A = PIOA_BASE_ADDRESS,
    PIO_PORT_B = PIOB_BASE_ADDRESS,
    PIO_PORT_D = PIOD_BASE_ADDRESS,
} PIO_PORT;

// *****************************************************************************
/* PIO Port Pins

  Summary:
    Identifies the available PIO port pins.

  Description:
    This enumeration identifies the available PIO port pins.

  Remarks:
    The caller should not rely on the specific numbers assigned to any of
    these values as they may change from one processor to the next.

    Not all pins are available on all devices.  Refer to the specific
    device data sheet to determine which pins are supported.
*/

typedef enum
{
    PIO_PIN_PA0 = 0,
    PIO_PIN_PA1 = 1,
    PIO_PIN_PA2 = 2,
    PIO_PIN_PA3 = 3,
    PIO_PIN_PA4 = 4,
    PIO_PIN_PA5 = 5,
    PIO_PIN_PA7 = 7,
    PIO_PIN_PA8 = 8,
    PIO_PIN_PA9 = 9,
    PIO_PIN_PA10 = 10,
    PIO_PIN_PA11 = 11,
    PIO_PIN_PA12 = 12,
    PIO_PIN_PA13 = 13,
    PIO_PIN_PA14 = 14,
    PIO_PIN_PA15 = 15,
    PIO_PIN_PA16 = 16,
    PIO_PIN_PA17 = 17,
    PIO_PIN_PA18 = 18,
    PIO_PIN_PA19 = 19,
    PIO_PIN_PA20 = 20,
    PIO_PIN_PA21 = 21,
    PIO_PIN_PA22 = 22,
    PIO_PIN_PA23 = 23,
    PIO_PIN_PA24 = 24,
    PIO_PIN_PA25 = 25,
    PIO_PIN_PA26 = 26,
    PIO_PIN_PA27 = 27,
    PIO_PIN_PA28 = 28,
    PIO_PIN_PA30 = 30,
    PIO_PIN_PA31 = 31,
    PIO_PIN_PB0 = 32,
    PIO_PIN_PB1 = 33,
    PIO_PIN_PB2 = 34,
    PIO_PIN_PB3 = 35,
    PIO_PIN_PB4 = 36,
    PIO_PIN_PB5 = 37,
    PIO_PIN_PB6 = 38,
    PIO_PIN_PB7 = 39,
    PIO_PIN_PB8 = 40,
    PIO_PIN_PB9 = 41,
    PIO_PIN_PB12 = 44,
    PIO_PIN_PB13 = 45,
    PIO_PIN_PD0 = 96,
    PIO_PIN_PD1 = 97,
    PIO_PIN_PD2 = 98,
    PIO_PIN_PD3 = 99,
    PIO_PIN_PD4 = 100,
    PIO_PIN_PD5 = 101,
    PIO_PIN_PD6 = 102,
    PIO_PIN_PD7 = 103,
    PIO_PIN_PD8 = 104,
    PIO_PIN_PD9 = 105,
    PIO_PIN_PD10 = 106,
    PIO_PIN_PD11 = 107,
    PIO_PIN_PD12 = 108,
    PIO_PIN_PD13 = 109,
    PIO_PIN_PD14 = 110,
    PIO_PIN_PD15 = 111,
    PIO_PIN_PD16 = 112,
    PIO_PIN_PD17 = 113,
    PIO_PIN_PD18 = 114,
    PIO_PIN_PD19 = 115,
    PIO_PIN_PD20 = 116,
    PIO_PIN_PD21 = 117,
    PIO_PIN_PD22 = 118,
    PIO_PIN_PD24 = 120,
    PIO_PIN_PD25 = 121,
    PIO_PIN_PD26 = 122,
    PIO_PIN_PD27 = 123,
    PIO_PIN_PD28 = 124,
    PIO_PIN_PD30 = 126,
    PIO_PIN_PD31 = 127,

    /* This element should not be used in any of the PIO APIs.
       It will be used by other modules or application to denote that none of the PIO Pin is used */
    PIO_PIN_NONE = -1

} PIO_PIN;


void PIO_Initialize(void);

// *****************************************************************************
// *****************************************************************************
// Section: PIO Functions which operates on multiple pins of a port
// *****************************************************************************
// *****************************************************************************

uint32_t PIO_PortRead(PIO_PORT port);

void PIO_PortWrite(PIO_PORT port, uint32_t mask, uint32_t value);

uint32_t PIO_PortLatchRead ( PIO_PORT port );

void PIO_PortSet(PIO_PORT port, uint32_t mask);

void PIO_PortClear(PIO_PORT port, uint32_t mask);

void PIO_PortToggle(PIO_PORT port, uint32_t mask);

void PIO_PortInputEnable(PIO_PORT port, uint32_t mask);

void PIO_PortOutputEnable(PIO_PORT port, uint32_t mask);
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

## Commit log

2021-10-08 Initial Kicad project
    [SAMduino.kicad_pcb, SAMduino.sch]
2021-10-10 Partial schematic
    [SAMduino.sch, external.sch, leds.sch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]
2021-10-11 Specialty pins wired
    [SAMduino.sch, external.sch, leds.sch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]
2021-10-12 All pins connected
    [SAMduino.sch, external.sch, leds.sch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]
2021-10-14 Schematic with footprints
    Some footprints need to be verified with actual components
    [BOM.xlsx, SAMduino.sch, external.sch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]
2021-10-15 Ready for PCB
    [leds.sch]
2021-10-15 Start of pcb layout. Rules set.
    [SAMduino.kicad_pcb]
2021-10-15 Almost routed - first attempt
    [SAMduino.kicad_pcb]
2021-10-15 Changed MCP2221 RST connection
    Removed some comments
    [external.sch, leds.sch]
2021-10-15 PCB routed - needs optimization
    [SAMduino.kicad_pcb, external.sch]
2021-10-16 Some silkscreen done
    Prior to swapping ICSP pins
    [SAMduino.kicad_pcb]
2021-10-16 Swapped program header to match PicKit4
    [SAMduino.kicad_pcb, leds.sch]
2021-10-16 Full PCB layout
    [SAMduino.kicad_pcb, leds.sch]
2021-10-16 Minor fixes to PCB
    [SAMduino.kicad_pcb]
2021-10-16 Updated BOM
    [BOM.xlsx]
2021-10-17 Generated gerbers
    [SAMduino-B_Cu.gbr, SAMduino-B_Mask.gbr, SAMduino-B_SilkS.gbr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]
2021-10-18 Minor PCB improvements
    [SAMduino-B_Cu.gbr, SAMduino-B_Mask.gbr, SAMduino-B_SilkS.gbr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]
2021-10-18 Changed oscillator to 3.2x2.5 size
    [SAMduino-B_Cu.gbr, SAMduino-B_Mask.gbr, SAMduino-B_SilkS.gbr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]
2021-10-19 Changed gerber parameters
    Set to JLPCB suggested values
    [SAMduino-B_Cu.gbl, SAMduino-B_Mask.gbs, SAMduino-B_SilkS.gbo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]
2021-10-19 Updated gerber settings
    [SAMduino.kicad_pcb]
2021-10-21 Changed voltage regulators
    [SAMduino.kicad_pcb, power.sch]
2021-10-22 Removed D10
    [BOM.xlsx, SAMduino.kicad_pcb, power.sch]
2021-10-22 Final gerbers
    [SAMduino-B_Cu.gbl, SAMduino-B_Mask.gbs, SAMduino-B_SilkS.gbo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]
2021-10-23 Changed via size
    [SAMduino-B_Cu.gbl, SAMduino-B_Mask.gbs, SAMduino-B_SilkS.gbo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]
2021-10-23 Finalized schematic V1.0
    [SAMduino.sch, external.sch, leds.sch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]
2021-10-27 Initial Harmony project
    [SAMduino.kicad_pcb]
2021-11-12 Fixed button labels on silkscreen
    [SAMduino.kicad_pcb]
2021-11-12 Buttons and LEDs tested.
    Running code with internal oscillator
    [main.c, plib_pio.c, plib_pio.h]
2021-11-13 UART0 and timer tested
2021-11-13 Different timer clocks
2021-11-13 Working CDC demo - High Speed USB
    [configuration.h]
2021-11-14 Fixed CAN connector labels and added errata
    [SAMduino.kicad_pcb]
2021-11-15 Initial SQI code - not all working
    [configuration.h]
2021-11-17 Fresh start on QSPI
    [configuration.h]
2021-11-18 Got SQI working
    [configuration.h]
2021-11-19 Full Demo code - Menu, buttons and leds working
2021-11-20 SQI flash demo working
    [configuration.h]
2021-11-21 CAN RX working (no interrupts)
2021-11-21 CAN interrupts working
2021-11-21 Removed test projects
    These are now included in FullDemo
    [configuration.h]
2021-11-23 ADC working
2021-11-24 USB enumerates.
    [configuration.h]
2021-11-24 Adjusted task and interrupt priorities
2021-11-24 USB attach and detach working
2021-11-24 Mouse is working
    [configuration.h]
2021-11-24 Removed test project
    [configuration.h]
2021-11-25 Changed UART RX to interrupt instead of task
2021-11-25 Adjusted interrupt priorities
2021-11-26 Changed drive strength on LED pins
2021-11-28 PWM working
2021-12-02 Added MSD with SQI flash demo
    [configuration.h]
2021-12-03 Added file system to MSD demo
    [configuration.h]
2021-12-04 Initial DMA demo
2021-12-04 DMA demo working
2021-12-06 Added USB bootloader demo
    [configuration.h]
2021-12-07 Switched to SYS_TIME for lcd delay
    [configuration.h]
2021-12-07 Moved DAC timer to TC0 - removed TC3
2021-12-08 Added quadrature encoder
2022-01-19 Converted to KiCad 6
    [SAMduino.kicad_pcb, SAMduino.kicad_sch, SAMduino.sch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]
